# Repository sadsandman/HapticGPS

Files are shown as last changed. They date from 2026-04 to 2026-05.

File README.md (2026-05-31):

# HapticGPS — Wearable Haptic Navigation Board

<p align="center">
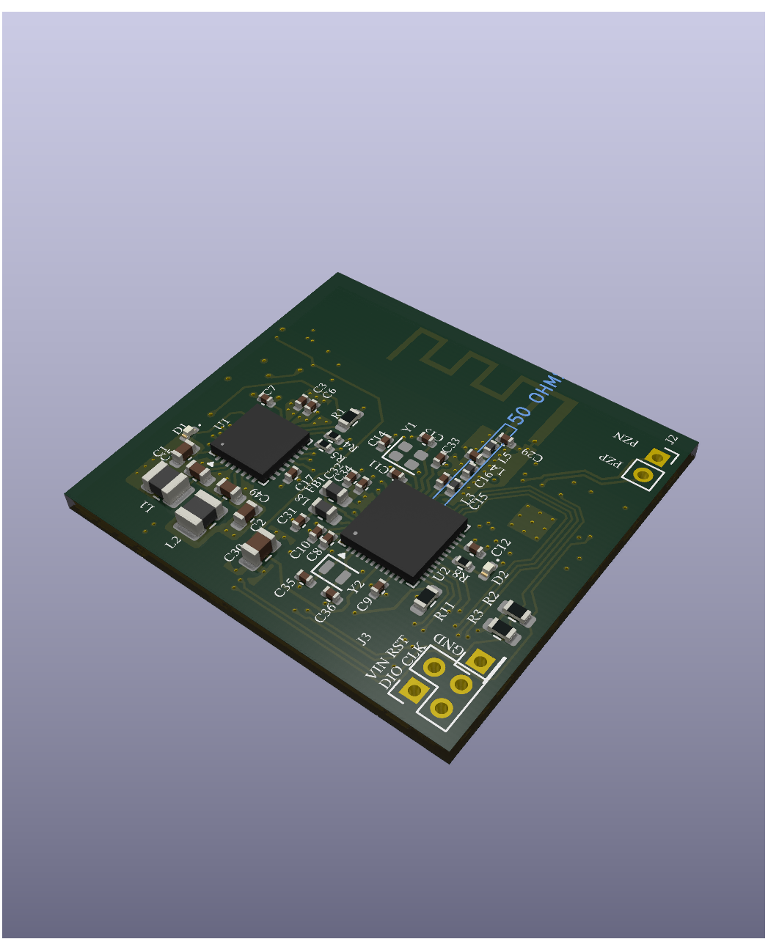
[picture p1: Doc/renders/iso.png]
HapticGPS PCB — isometric view
  
</p>

<p align="center">
  
  
  
  
</p>

A compact 4-layer wearable PCB that delivers directional haptic feedback via a piezoelectric actuator. The board combines a Bluetooth Low Energy SoC, a 6-axis IMU, a piezoelectric haptic driver, non-volatile FRAM storage, and a LiPo power management IC — all in a **30 × 33 mm** footprint.

---

## PCB Views

| Top | Bottom |
|:---:|:---:|
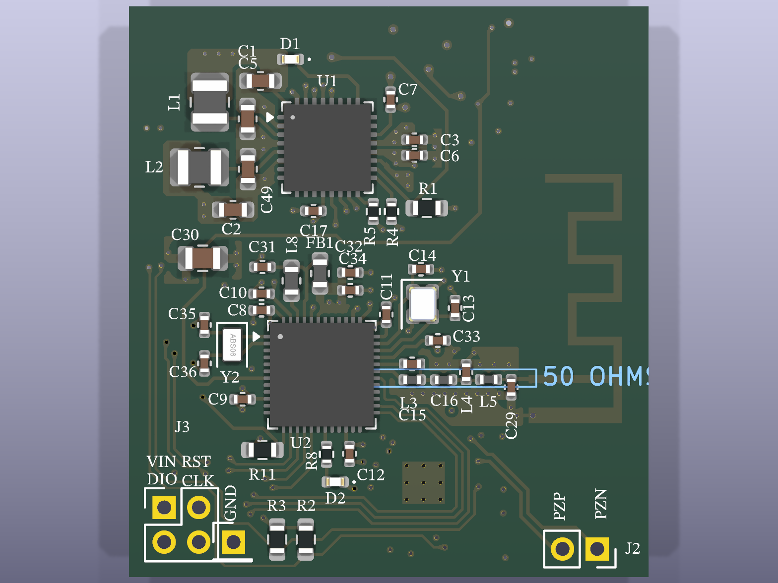
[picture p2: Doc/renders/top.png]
Top view
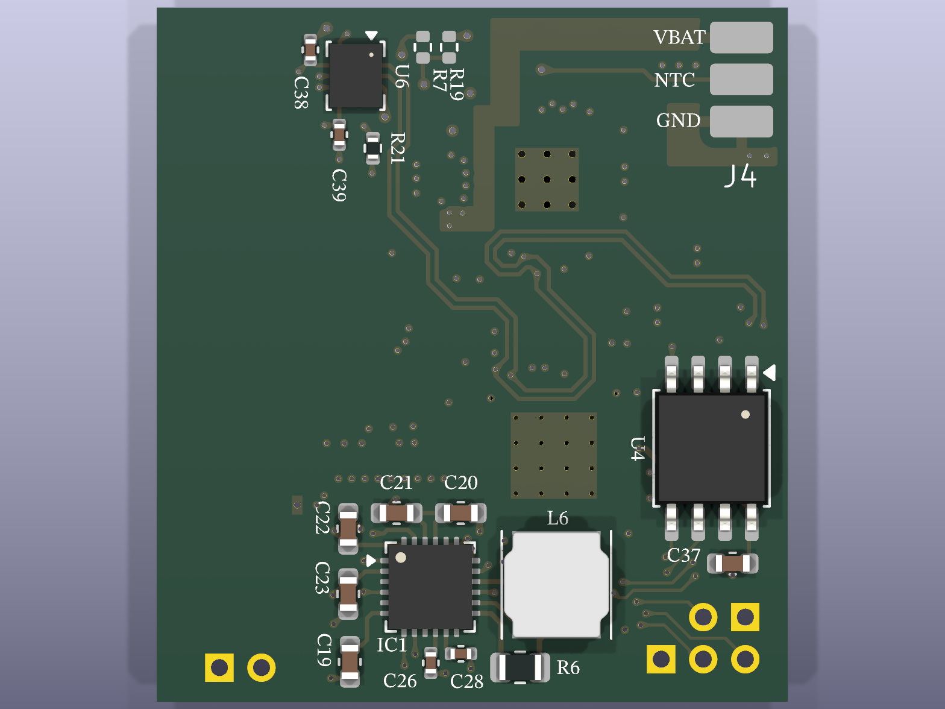
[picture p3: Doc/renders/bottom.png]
Bottom view
|  |  |

---

## Key Features

- **Ultra-low-power BLE 5.4** SoC (Nordic nRF54L15) with on-board PCB trace antenna
- **Piezoelectric haptic feedback** driven by a dedicated high-voltage driver IC (Bosch BOS1921)
- **6-axis IMU** (ST LSM6DSV) for orientation and motion sensing
- **8 Mbit FRAM** (Cypress CY15B108QN) for fast, wear-unlimited non-volatile storage
- **Integrated LiPo charger + dual DCDC + LDO** (Nordic nPM1300 PMIC)
- **4-layer stackup** for clean power planes and antenna isolation
- SWD debug/programming header

---

## Hardware Specifications

| Parameter | Value |
|---|---|
| PCB size | 30 × 33 mm |
| Stackup | 4-layer (F.Cu / In1.Cu / In2.Cu / B.Cu) |
| Board thickness | 1.526 mm |
| Design tool | KiCad 9.0 |
| Revision | V1.0.0 |

---

## Block Diagram

<p align="center">
  System architecture
</p>

---

## Bill of Materials (Key ICs)

| Ref | Part | Description |
|-----|---|---|
| U1 | [Nordic nPM1300](https://www.nordicsemi.com/Products/nPM1300) | PMIC — LiPo charger, dual buck, LDO |
| U2 | [Nordic nRF54L15-QFAA-R](https://www.nordicsemi.com/Products/nRF54L15) | BLE 5.4 SoC, Arm Cortex-M33 |
| U3 | [Bosch BOS1921CQR](https://www.bosch-sensortec.com) | Piezoelectric haptic driver |
| U4 | [Cypress CY15B108QN](https://www.infineon.com/cms/en/product/memories/f-ram-ferroelectric-ram/serial-f-ram/cy15b108qn/) | 8 Mbit SPI FRAM |
| IC1 | [ST LSM6DSV80XTR](https://www.st.com/en/mems-and-sensors/lsm6dsv80x.html) | 6-axis IMU (accel + gyro) |
| Y1/Y2 | Crystal | MCU system & RTC clock references |

---

## Connectors & Interfaces

| Designator | Function | Signals |
|---|---|---|
| J3 | SWD debug header | VIN, RST, DIO, CLK, GND |
| J4 | LiPo battery | VBAT, NTC, GND |
| J2 | Piezo actuator | PZP, PZN |

---

## Getting Started

### Prerequisites

- [KiCad 9.0+](https://www.kicad.org/) to open schematics and PCB layout
- A LiPo cell (connected via J4)
- A piezoelectric actuator (connected via J2)
- An SWD programmer (e.g. J-Link, nRF9160 DK) for firmware flashing

### Opening the Project

```bash
git clone <repo-url>
cd HapticGPS/HapticGPS
kicad HapticGPS.kicad_pro
```

### Generating PCB Renders

Renders are generated with the KiCad CLI:

```bash
# Top view
kicad-cli pcb render \
  --output Doc/renders/top.png \
  --width 1600 --height 1200 \
  --side top --quality high --floor \
  HapticGPS/HapticGPS.kicad_pcb

# Bottom view
kicad-cli pcb render \
  --output Doc/renders/bottom.png \
  --width 1600 --height 1200 \
  --side bottom --quality high --floor \
  HapticGPS/HapticGPS.kicad_pcb

# Isometric view
kicad-cli pcb render \
  --output Doc/renders/iso.png \
  --width 1600 --height 1200 \
  --quality high --floor --perspective \
  --rotate "30,0,45" \
  HapticGPS/HapticGPS.kicad_pcb
```

---

## Repository Structure

```
HapticGPS/
├── HapticGPS/
│   ├── HapticGPS.kicad_pro       # KiCad project file
│   ├── HapticGPS.kicad_pcb       # PCB layout
│   ├── HapticGPS.kicad_sch       # Top-level schematic
│   └── modules/
│       ├── controller.sch.kicad_sch     # MCU + FRAM
│       ├── power.kicad_sch              # PMIC circuit
│       ├── piezoelectric_driver.kicad_sch  # Haptic driver
│       └── (imu.kicad_sch)              # IMU sub-sheet
└── Doc/
    ├── architecture/
    │   └── Basic_architecture.svg
    └── renders/
        ├── top.png
        ├── bottom.png
        └── iso.png
```

---

## License

This hardware design is released under the **CERN Open Hardware Licence Version 2 — Strongly Reciprocal (CERN-OHL-S v2)**.  
See [`LICENSE`](LICENSE) for the full text, or visit [ohwr.org/cern_ohl_s_v2.txt](https://ohwr.org/cern_ohl_s_v2.txt).

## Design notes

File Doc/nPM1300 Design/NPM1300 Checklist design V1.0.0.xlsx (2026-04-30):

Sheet: Schematic checklist
nPM1300 Schematic Checklist |  | Date: | 11.12.2025 |  |  |  |  |  |  | OK
 |  |  |  |  |  |  |  |  |  | NOK
Pin QFN | Pin CSP | Pin Name | Direction | Type | OpMax [V] | AbsMax [V] | Function | Connection | Component spec | Reviewed | Review Notes
1 | B6 | VOUT1 | Input | Analog |  | 5.5 | Buck1 output voltage feedback | Connect to Buck1 output capacitor. Connect to PVDD if not used for biasing it to known level and avoiding leakage. | Capacitance 10uF nominal Min 4uF effective Max 20uF effective Voltage rating 6.3V or higher Increasing capacitance has effect on the startup time and VSYS drop during startup. If both bucks are used they start at the same time and loading to the VSYS rail need to be considered (100mA default current limit). | OK | Check DC bias effect of the capacitor
2 | A7 | PVSS1 |  | Ground | 0 | 0 | Buck1 power stage ground | Connect to GND |  | OK
3 | B7 | SW1 | Output | Power |  | 5.5 | Buck1 switch output to inductor | Connect to output inductor. Leave floating if not used | rr | OK
4 | C7 | PVDD | Input | Power |  | 5.5 | Power input for both buck converters | Connect to VSYS. Must have input capacitor for each used buck. Capacitors must be grounded to PVSS1/PVSS2 accordingly | Capacitance 10uF nominal per buck in use Min 4uF effective Voltage rating 6.3V or higher Consider adding smaller high frequency bypass capacitor for each buck input (10nF or 100nF) for EMI reduction | OK | Check DC bias effect of the capacitor
5 | D7 | SW2 | Output | Power |  | 5.5 | Buck2 switch output to inductor | Connect to output inductor. Leave floating if not used | Inductance 2.2uH (+/-20%) ISAT >350mA ITEMP >200mA DCR < 400mohm
6 | E7 | PVSS2 |  | Ground | 0 | 0 | Buck2 power stage ground | Connect to GND |  | OK
7 | D6 | GPIO0 | Input/output | Digital |  | VDDIO + 0.3 | General purpose IO | User defined. Can be left floating if not used |  | OK
8 | E6 | GPIO1 | Input/output | Digital |  | VDDIO + 0.3 | General purpose IO | User defined. Can be left floating if not used |  | OK
9 | C5 | GPIO2 | Input/output | Digital |  | VDDIO + 0.3 | General purpose IO | User defined. Can be left floating if not used |  | OK
10 | C4 | GPIO3 | Input/output | Digital |  | VDDIO + 0.3 | General purpose IO | User defined. Can be left floating if not used |  | OK
11 | B5 | GPIO4 | Input/output | Digital |  | VDDIO + 0.3 | General purpose IO | User defined. Can be left floating if not used |  | OK
12 | E4 | VDDIO | Input | Power | VSYS | 5.5 | IO reference voltage supply | Should be connected to desired IO voltage level used for TWI bus | Capacitance 100nF nominal Voltage rating 6.3V or higher | OK
13 | E5 | SDA | Input/output | Digital |  | VDDIO + 0.3 | TWI Data line | Pull-up resistor to VDDIO. Connect to GND or VDDIO if not used | Resistor value depends on the bus capacitance and TWI clock frequency | OK
14 | E3 | SCL | Input | Digital |  | VDDIO + 0.3 | TWI Clock line | Pull-up resistor to VDDIO. Connect to GND or VDDIO if not used | Resistor value depends on the bus capacitance and TWI clock frequency | OK
15 | D4 | SHPHLD | Input | Digital |  | 5.5 | Ship hold mode control | Typically push button to GND to allow exiting Ship mode. Can be left floating if not used. There is internal 50kohm pull-up to VBAT. Don't connect to SoC GPIO or similar directly configured as push-pull output. It will can form a leakage path through the internal pull-up resistor. Ok to connect to Open Drain output.
16 | E1 | VSET2 | Input | Analog |  | 5.5 | Set resistor for default Buck2 output voltage | Connect to RVSET2. Connect to GND for disabling Buck2 by default. Note: even if buck is disabled by default it can be enabled with TWI. |  | OK
17 | E2 | VSET1 | Input | Analog |  | 5.5 | Set resistor for default Buck1 output voltage | Connect to RVSET1. Connect to GND for disabling Buck1 by default. Note: even if buck is disabled by default it can be enabled with TWI. |  | OK
18 | D3 | NTC | Input | Analog |  | 5.5 | Battery NTC thermistor input | Connect to battery NTC. If battery pack does not have NTC connect this pin directly or through a resistor to GND. Functionality must be disabled with TWI write. | Parallel capacitance max 100pF | OK | Check battery datasheet for parallel capacitance on the NTC
19 | D1,D2 | VBAT | Input | Power | 4.45 | 5.5 | Battery input | Connect to bypass capacitor and battery | Capacitance 2.2uF nominal recommended Voltage rating 6.3V or higher | OK
20 | C1/C2 | VSYS | Output | Power |  | 5.5 | System regulator output | Connect to PVDD and to VSYS capacitor | Capacitance 10uF nominal 4uF effective minimum Voltage rating 6.3V or higher in addition to the buck input capacitors placed on PVDD Consider adding smaller high frequency bypass capacitor (10nF or 100nF) for EMI reduction | OK | Check DC bias effect of the capacitor
21 | B1, B2 | VBUS | Input | Power | 5.5 | 22 | USB supply | Connect to USB VBUS and VBUSIN capacitor | Capacitance 1uF nominal See USB specification for max capacitance limitations. Check carefully the voltage rating of the capacitor for the use case. Voltage rating of the VBUS pin is 22V and if up to 22V voltage transients are expected the capacitor should be selected accordingly. | NOK
22 | C3 | VBUSOUT | Output | Analog |  | 5.5 | VBUSOUT | Connect to nRF device VBUS. Must have decoupling capacitor even if not used. VBUSOUT is only for host sensing and should not be used as a supply | Capacitance 1uF nominal Voltage rating 6.3V or higher | OK
23 | D5 | CC1 | Input | Analog |  | 5.5 | USB-C Configuration Channel 1 | Connect to USB-C connector CC1. Leave floating if USB-C is not used, or connect to GND. Internal 5.1kohm resistor |  | OK
24 | B3 | CC2 | Input | Analog |  | 5.5 | USB-C Configuration Channel 2 | Connect to USB-C connector CC2. Leave floating if USB-C is not used, or connect to GND. Internal 5.1kohm resistor |  | OK
25 | A1 | LED0 | Output | Analog |  | 5.5 | Led driver 0 output, 5mA constant current sink | Connect to LED cathode. Leave floating if not used |  | OK
26 | A2 | LED1 | Output | Analog |  | 5.5 | Led driver 1 output, 5mA constant current sink | Connect to LED cathode. Leave floating if not used |  | OK
27 | A3 | LED2 | Output | Analog |  | 5.5 | Led driver 2 output, 5mA constant current sink | Connect to LED cathode. Leave floating if not used |  | OK
28 | B4 | LSIN1/VINLDO1 | Input | Power |  | 5.5 | Load switch/LDO1 input | Connect to supply for load switch/LDO1. Connect to GND if not used | Input capacitance depends on what supplies the load switch/LDO. If connected to buck output or VSYS, typically no additional capacitance needed. Minimum input voltage in LDO mode is 2.6V. | OK
29 | A4 | LSOUT1/VOUTLDO1 | Output | Power |  | 5.5 | Load switch/LDO1 output | Connect to output capacitor. Connect to GND if not used | LDO Operation: Capacitance 2x10uF nominal 6uF effective minimum Voltage rating 6.3V or higher LS operation: Capacitance 1uF nominal Voltage rating 6.3V or higher | OK | Check DC bias effect of the capacitor
30 | B5 | LSIN2/VINLDO2 | Input | Power |  | 5.5 | Load switch/LDO2 input | Connect to supply for load switch/LDO2. Connect to GND if not used | Input capacitance depends on what supplies the load switch/LDO. If connected to buck output or VSYS, typically no additional capacitance needed. Minimum input voltage in LDO mode is 2.6V. | OK
31 | A5 | LSOUT2/VOUTLDO2 | Output | Power |  | 5.5 | Load switch/LDO2 output | Connect to output capacitor. Connect to GND if not used | LDO Operation: Capacitance 2x10uF nominal 6uF effective minimum Voltage rating 6.3V or higher LS operation: Capacitance 1uF nominal Voltage rating 6.3V or higher | OK | Check DC bias effect of the capacitor
32 | C6 | VOUT2 | Input | Analog |  | 5.5 | Buck2 output voltage feedback | Connect to Buck2 output capacitor. Connect to PVDD if not used for biasing it to known level and avoiding leakage. | Capacitance 10uF nominal Min 4uF effective Max 20uF effective Voltage rating 6.3V or higher Increasing capacitance has effect on the startup time and VSYS drop during startup. If both bucks are used they start at the same time and loading to the VSYS rail need to be considered (100mA default current limit). | OK
DAP | A6 | AVSS |  | Ground | 0 | 0 | Analog/Digital ground | Connect to GND plane |  | OK
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

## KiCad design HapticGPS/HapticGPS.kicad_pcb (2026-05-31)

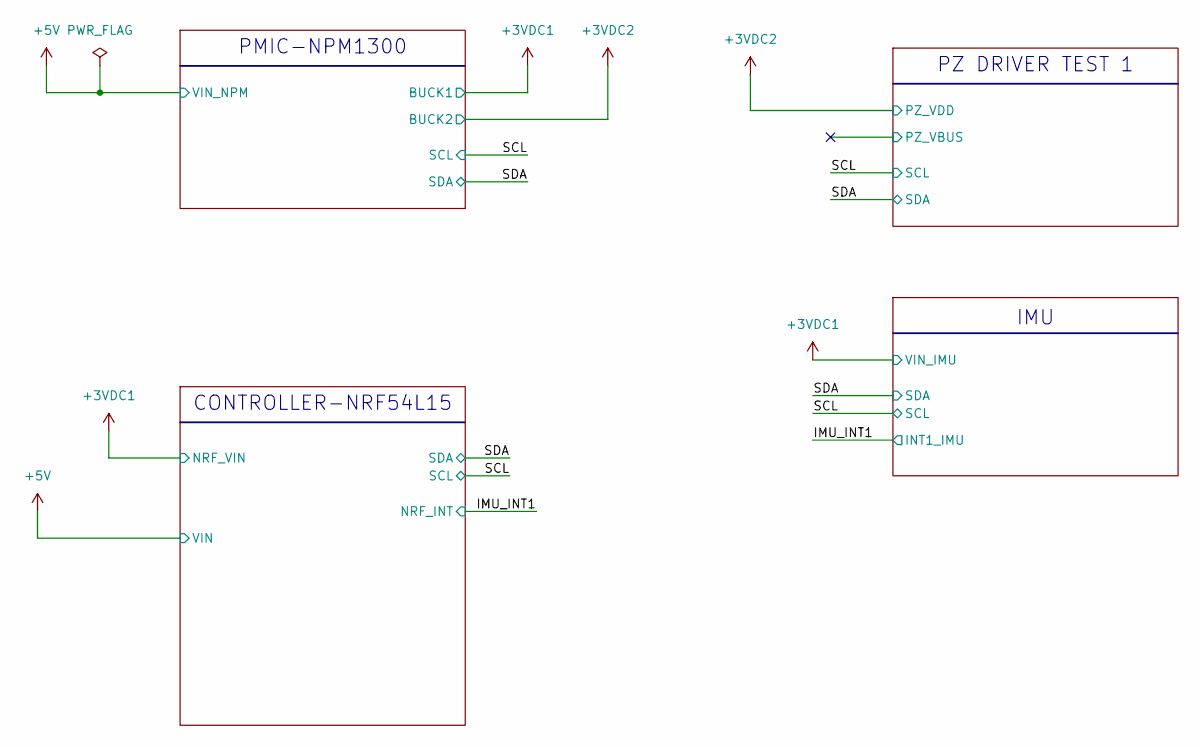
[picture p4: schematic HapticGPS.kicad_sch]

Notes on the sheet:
PMIC-NPM1300
IMU
PZ DRIVER TEST 1
CONTROLLER-NRF54L15

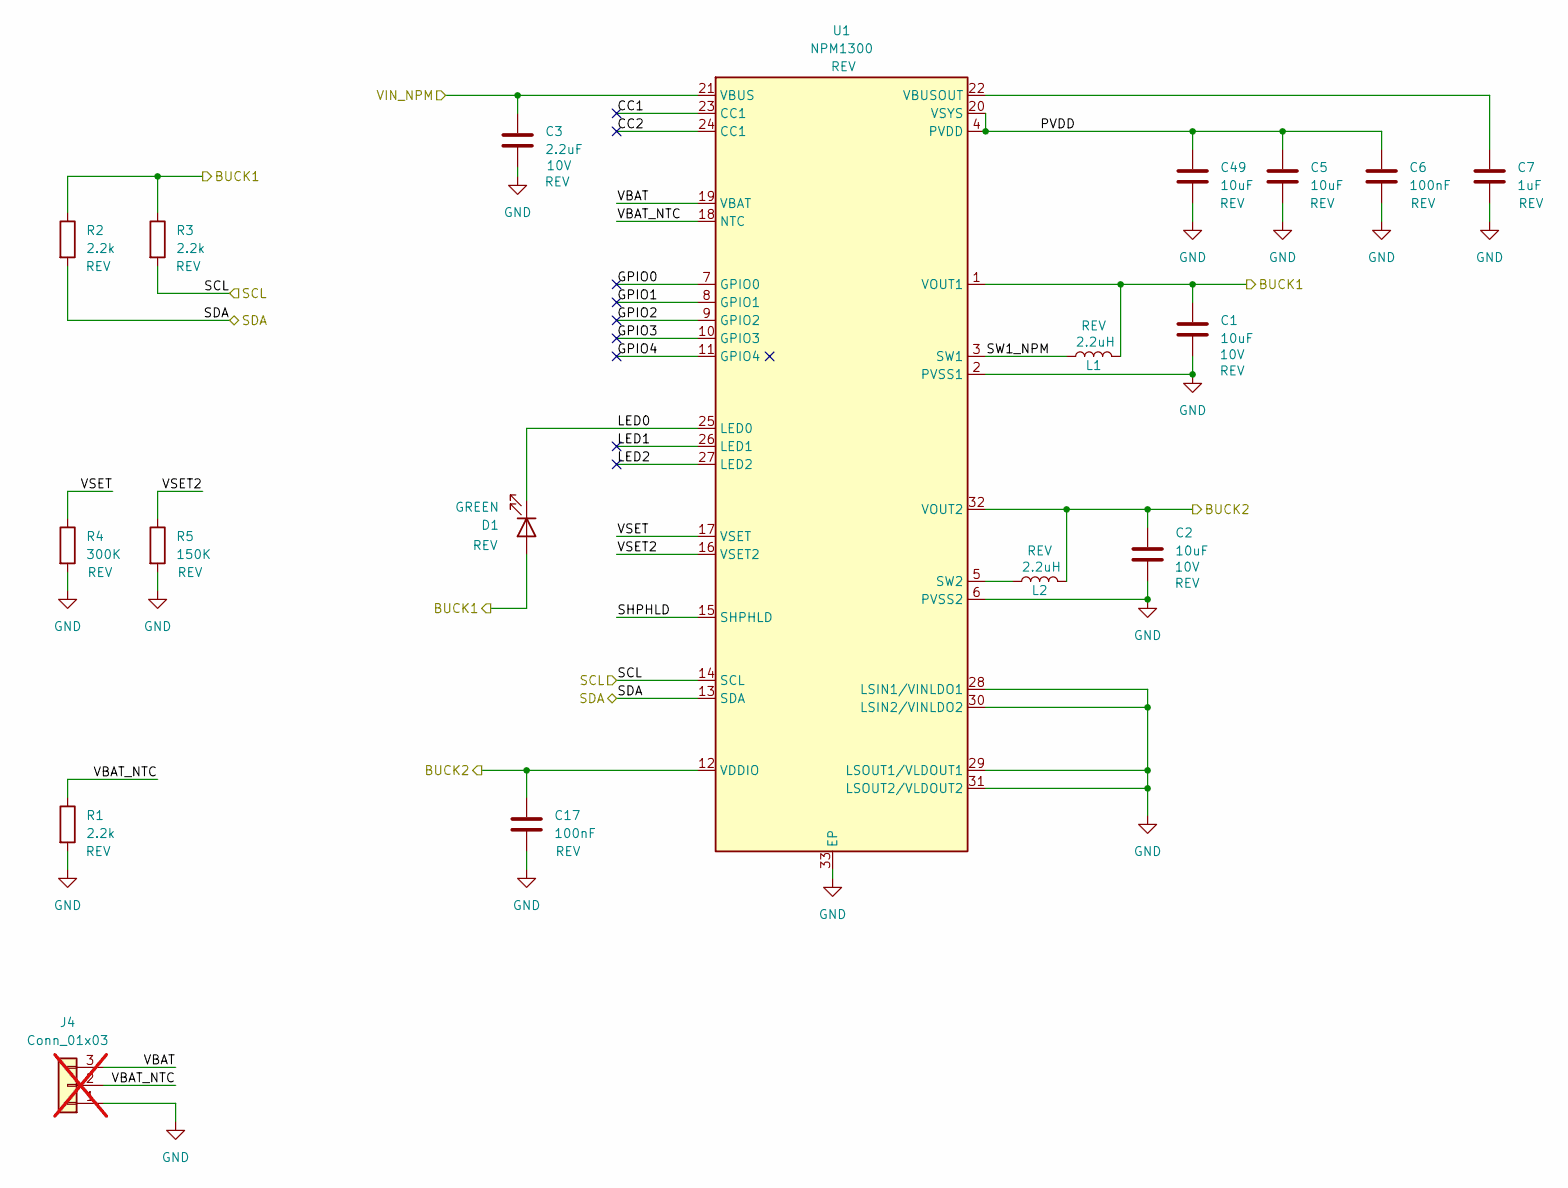
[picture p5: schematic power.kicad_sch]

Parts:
C1, C2: 10uF; C_0603_1608Metric; Voltage 10V
C3: 2.2uF; C_0402_1005Metric; Voltage 10V
C5, C49: 10uF; C_0603_1608Metric
C6, C17: 100nF; C_0402_1005Metric
C7: 1uF; C_0402_1005Metric
D1: GREEN; LED_0402_1005Metric
J4: Conn_01x03; 01x03_1.5x3; not fitted
L1, L2: 2.2uH; L_1008_2520Metric
R1, R2, R3: 2.2k; R_0603_1608Metric
R4: 300K; R_0402_1005Metric
R5: 150K; R_0402_1005Metric
U1: NPM1300; VQFN-32-1EP_5x5mm_P0.5mm_EP3.1x3.1mm_ThermalVias

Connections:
+3VDC1: C1.1, D1.2 (A), L1.2, R2.1, R3.1, U1.1 (VOUT1); also elsewhere on the board
+3VDC2: C2.1, C17.1, L2.2, U1.12 (VDDIO), U1.32 (VOUT2); also elsewhere on the board
+5V: C3.1, U1.21 (VBUS); also elsewhere on the board
/POWER/CC1: U1.23 (CC1)
/POWER/CC2: U1.24 (CC1)
/POWER/GPIO0: U1.7 (GPIO0)
/POWER/GPIO1: U1.8 (GPIO1)
/POWER/GPIO2: U1.9 (GPIO2)
/POWER/GPIO3: U1.10 (GPIO3)
/POWER/GPIO4: U1.11 (GPIO4)
/POWER/LED0: D1.1 (K), U1.25 (LED0)
/POWER/LED1: U1.26 (LED1)
/POWER/LED2: U1.27 (LED2)
/POWER/PVDD: C5.1, C6.1, C49.1, U1.4 (PVDD), U1.20 (VSYS)
/POWER/SHPHLD: U1.15 (SHPHLD)
/POWER/SW1_NPM: L1.1, U1.3 (SW1)
/POWER/VBAT: J4.3, U1.19 (VBAT)
/POWER/VBAT_NTC: J4.2, R1.1, U1.18 (NTC)
/POWER/VSET: R4.1, U1.17 (VSET)
/POWER/VSET2: R5.1, U1.16 (VSET2)
/SCL: R3.2, U1.14 (SCL); also elsewhere on the board
/SDA: R2.2, U1.13 (SDA); also elsewhere on the board
GND: C1.2, C2.2, C3.2, C5.2, C6.2, C7.2, C17.2, C49.2, J4.1, R1.2, R4.2, R5.2, U1.2 (PVSS1), U1.6 (PVSS2), U1.28 (LSIN1/VINLDO1), U1.29 (LSOUT1/VLDOUT1), U1.30 (LSIN2/VINLDO2), U1.31 (LSOUT2/VLDOUT2), U1.33 (EP); also elsewhere on the board
unnamed: L2.1, U1.5 (SW2)
unnamed: C7.1, U1.22 (VBUSOUT)

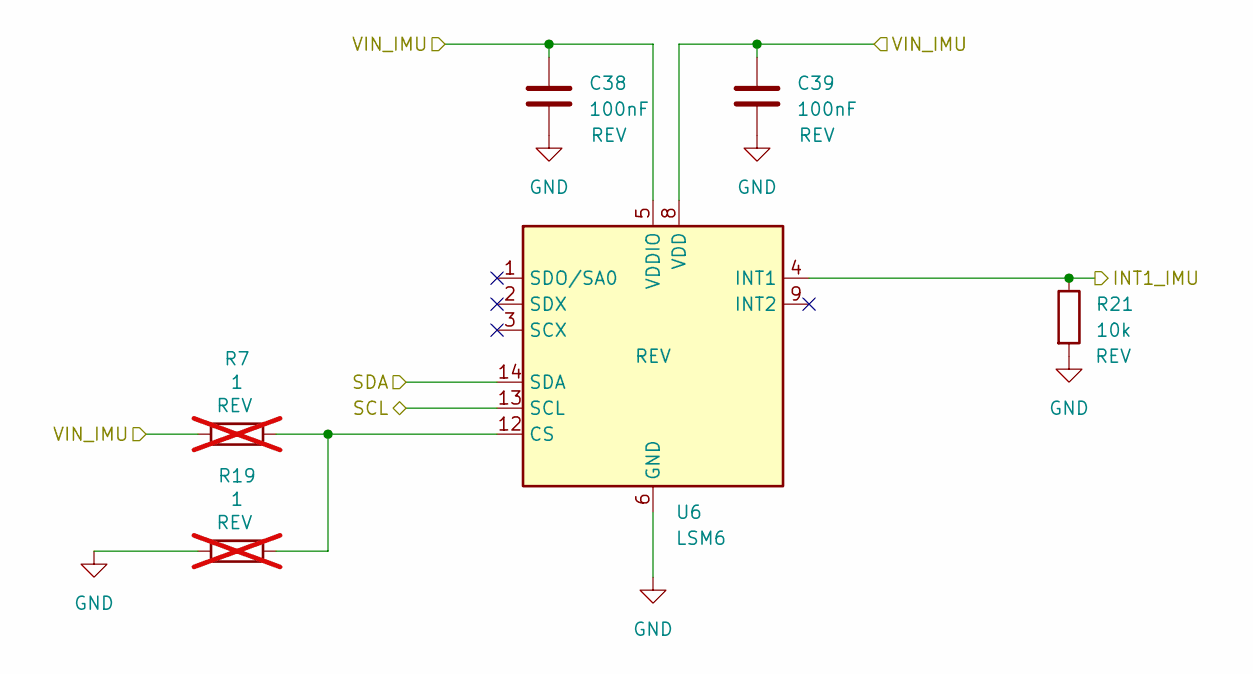
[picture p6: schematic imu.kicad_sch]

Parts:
C38, C39: 100nF; C_0402_1005Metric
R7, R19: 1; R_0402_1005Metric; not fitted
R21: 10k; R_0402_1005Metric
U6: LSM6; LGA-14_3x2.5mm_P0.5mm_LayoutBorder3x4y

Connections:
+3VDC1: C38.1, C39.1, R7.1, U6.5 (VDDIO), U6.8 (VDD); also elsewhere on the board
/IMU_INT1: R21.1, U6.4 (INT1); also elsewhere on the board
/SCL: U6.13 (SCL); also elsewhere on the board
/SDA: U6.14 (SDA); also elsewhere on the board
GND: C38.2, C39.2, R19.1, R21.2, U6.6 (GND), U6.7 (GND); also elsewhere on the board
unnamed: R7.2, R19.2, U6.12 (CS)

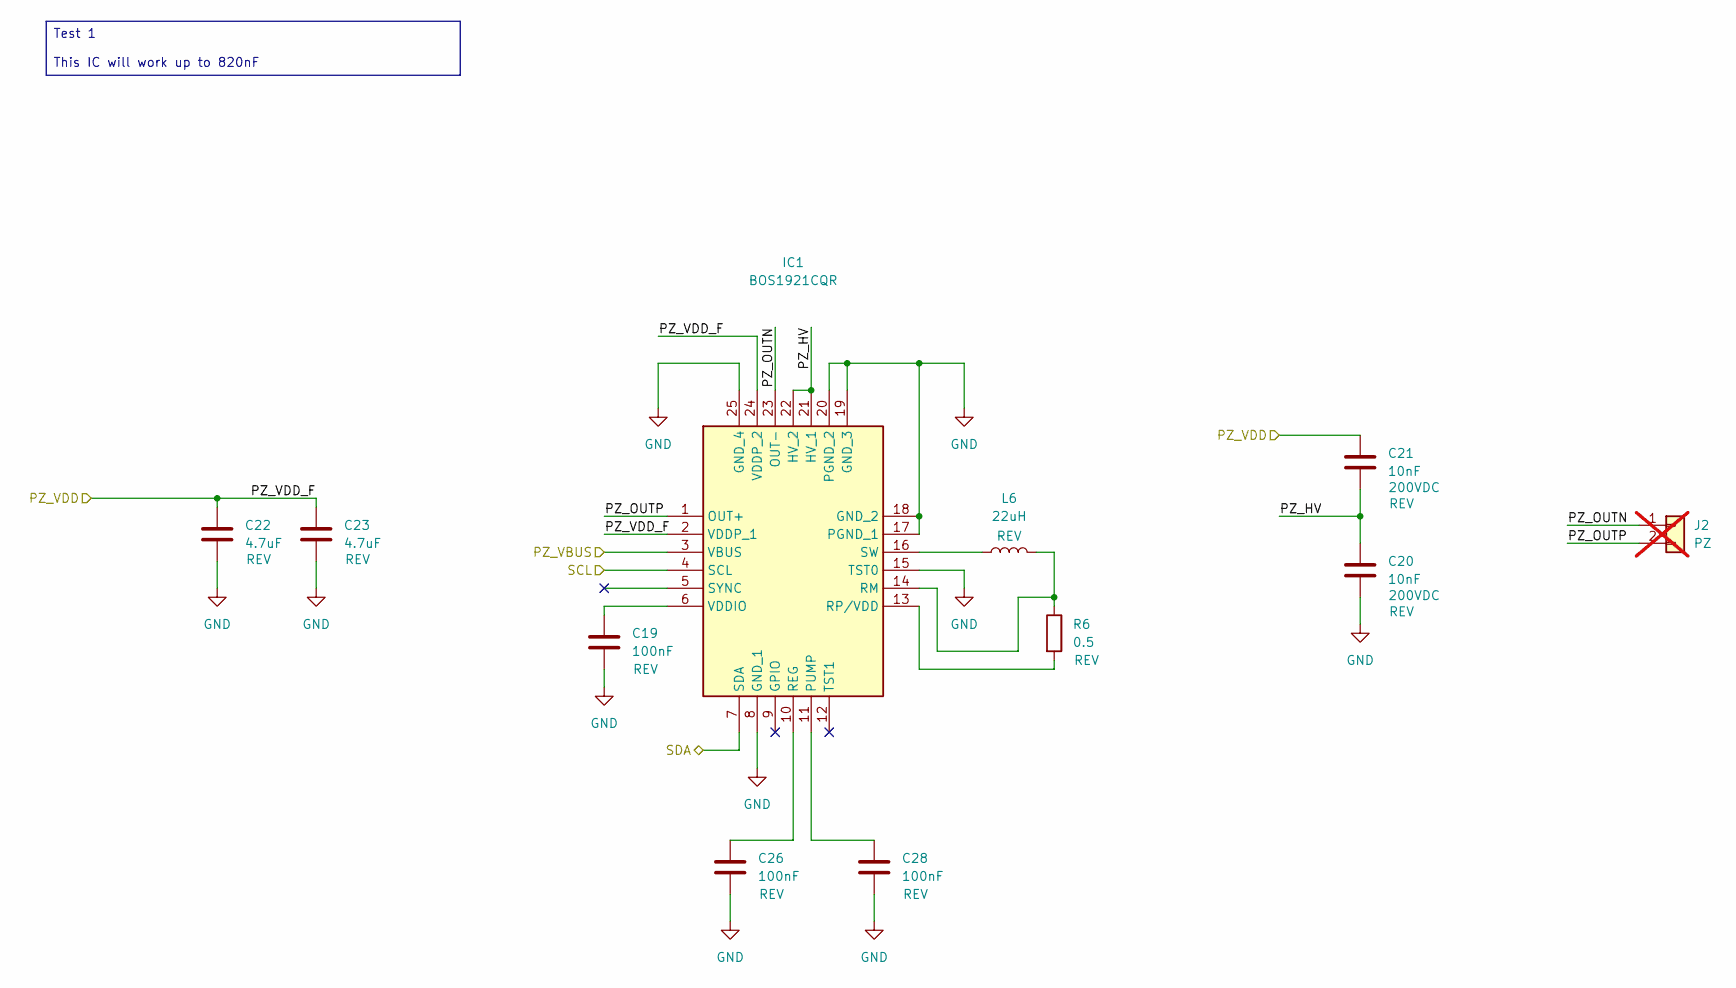
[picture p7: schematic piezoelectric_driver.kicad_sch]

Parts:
C19: 100nF; C_0603_1608Metric
C20, C21: 10nF; C_0603_1608Metric; Voltage 200VDC
C22, C23: 4.7uF; C_0603_1608Metric
C26, C28: 100nF; C_0402_1005Metric
IC1: BOS1921CQR; VQFN-24-1EP_4x4mm_P0.5mm_EP2.45x2.45mm_ThermalVias
J2: PZ; PinSocket_1x02_P2.00mm_Vertical; not fitted
L6: 22uH; L_Taiyo-Yuden_MD-5050
R6: 0.5; R_0805_2012Metric

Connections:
+3VDC2: C21.1, C22.2, C23.2, IC1.2 (VDDP_1), IC1.24 (VDDP_2); also elsewhere on the board
/PIEZOELECTRIC DRIVER/PZ_HV: C20.1, C21.2, IC1.21 (HV_1), IC1.22 (HV_2)
/PIEZOELECTRIC DRIVER/PZ_OUTN: IC1.23 (OUT-), J2.1
/PIEZOELECTRIC DRIVER/PZ_OUTP: IC1.1 (OUT+), J2.2
/PIEZOELECTRIC DRIVER/PZ_VBUS: IC1.3 (VBUS)
/SCL: IC1.4 (SCL); also elsewhere on the board
/SDA: IC1.7 (SDA); also elsewhere on the board
GND: C19.2, C20.2, C22.1, C23.1, C26.2, C28.2, IC1.8 (GND_1), IC1.15 (TST0), IC1.17 (PGND_1), IC1.18 (GND_2), IC1.19 (GND_3), IC1.20 (PGND_2), IC1.25 (GND_4); also elsewhere on the board
unnamed: C28.1, IC1.11 (PUMP)
unnamed: C26.1, IC1.10 (REG)
unnamed: IC1.14 (RM), L6.2, R6.1
unnamed: IC1.13 (RP/VDD), R6.2
unnamed: IC1.16 (SW), L6.1
unnamed: C19.1, IC1.6 (VDDIO)

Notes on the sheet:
Test 1 This IC will work up to 820nF

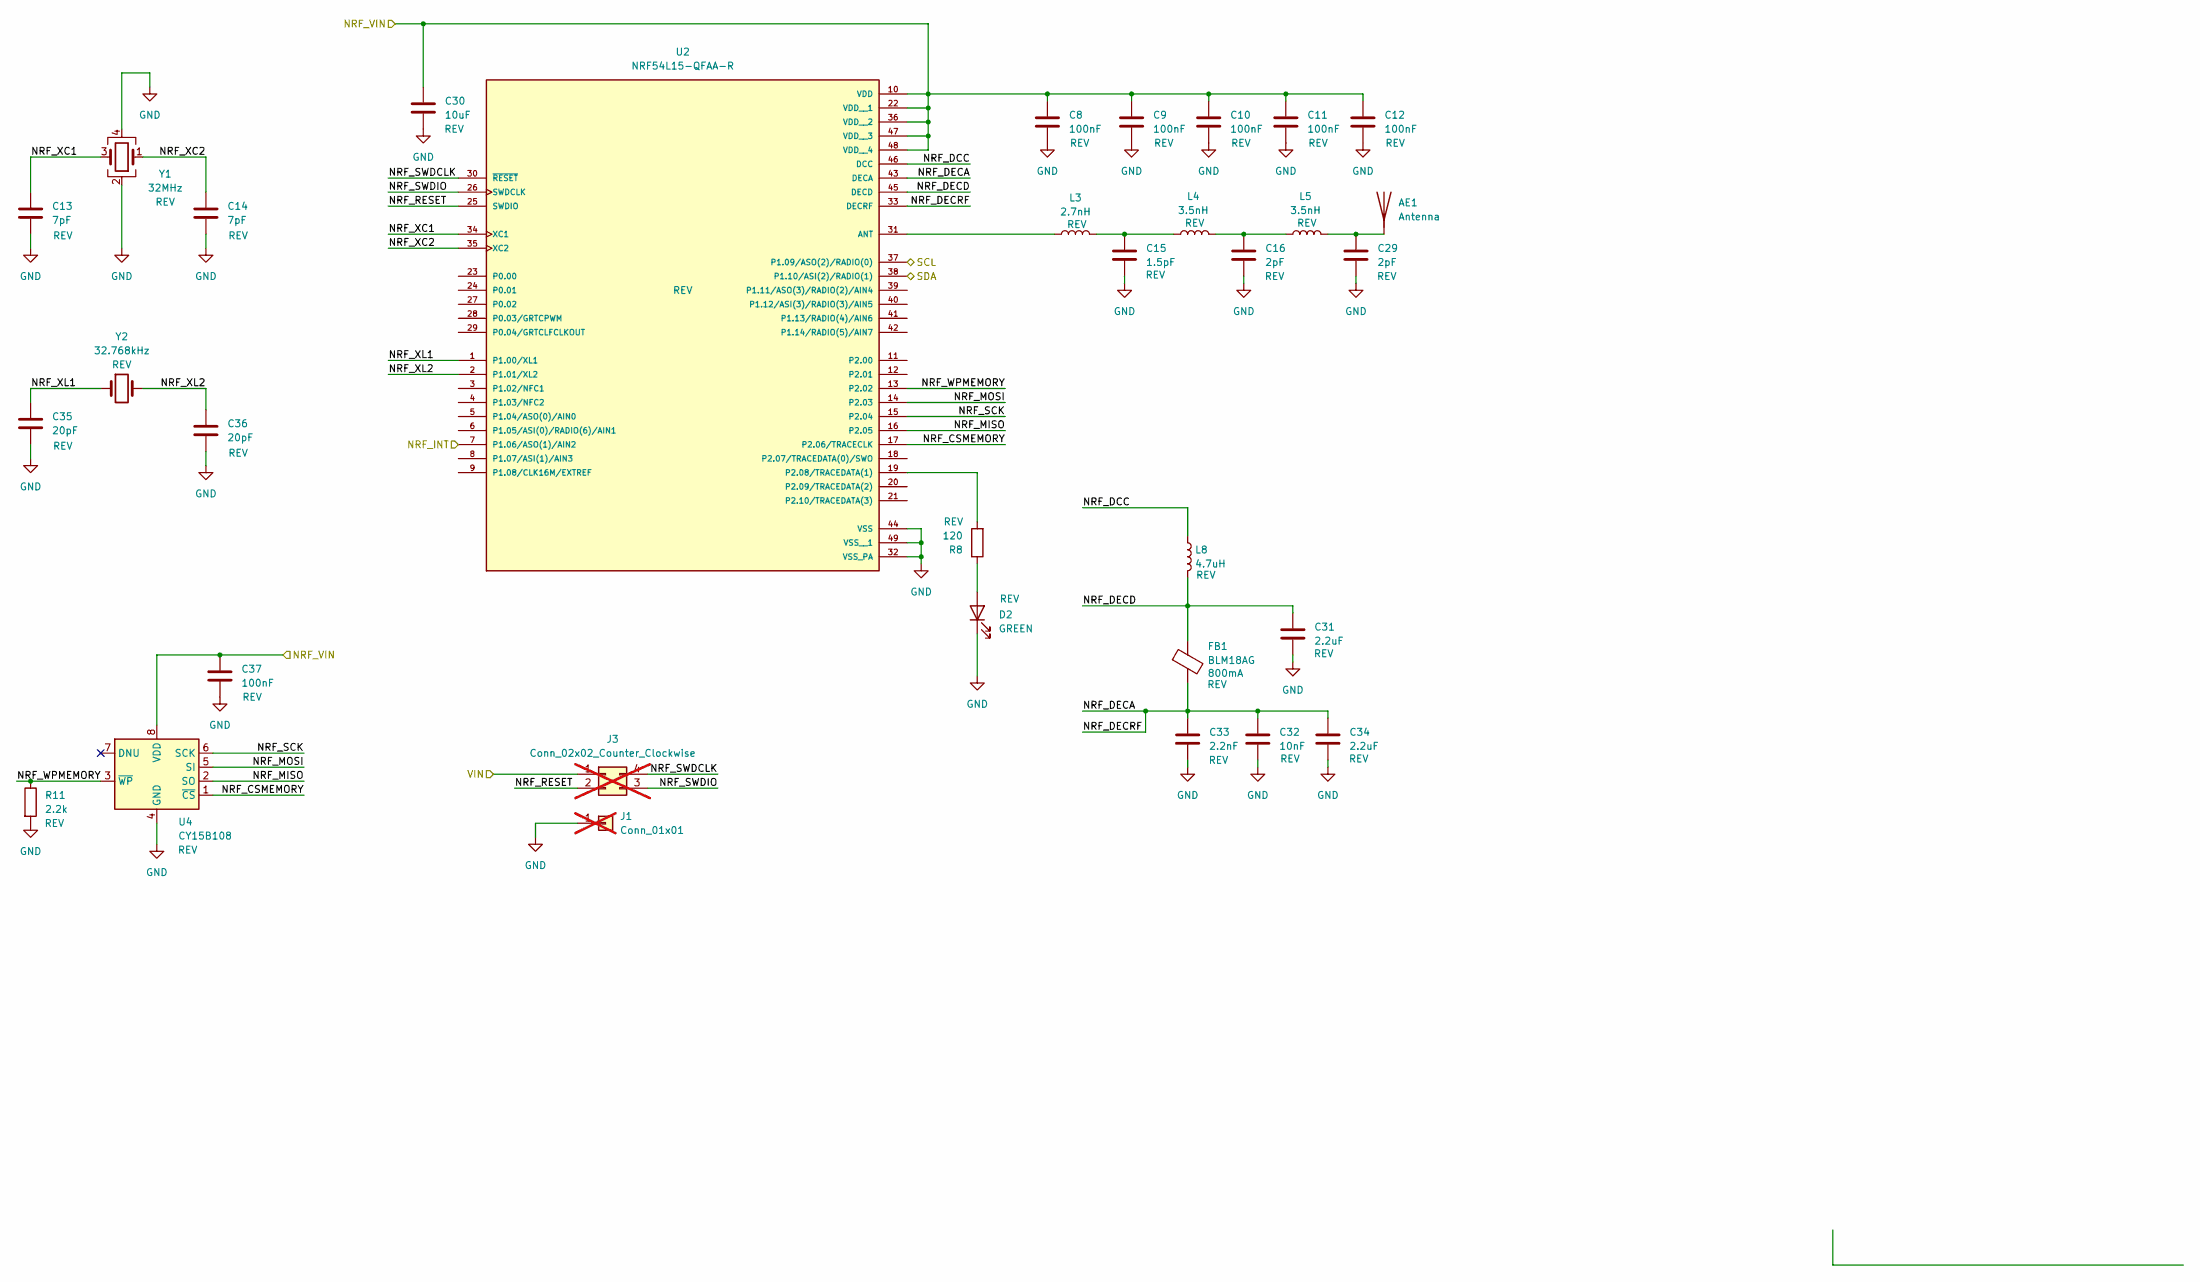
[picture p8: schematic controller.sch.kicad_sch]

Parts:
AE1: Antenna; Texas_SWRA117D_2.4GHz_Left
C8, C9, C10, C11, C12: 100nF; C_0402_1005Metric
C13, C14: 7pF; C_0402_1005Metric
C15: 1.5pF; C_0402_1005Metric
C16, C29: 2pF; C_0402_1005Metric
C30: 10uF; C_0805_2012Metric
C31, C34: 2.2uF; C_0402_1005Metric
C32: 10nF; C_0402_1005Metric
C33: 2.2nF; C_0402_1005Metric
C35, C36: 20pF; C_0402_1005Metric
C37: 100nF; C_0603_1608Metric
D2: GREEN; LED_0402_1005Metric
FB1: BLM18AG; L_0603_1608Metric
J1: Conn_01x01; PinHeader_1x01_P2.00mm_Vertical; not fitted
J3: Conn_02x02_Counter_Clockwise; not fitted
L3: 2.7nH; L_0402_1005Metric
L4, L5: 3.5nH; L_0402_1005Metric
L8: 4.7uH; L_0603_1608Metric
R8: 120; R_0402_1005Metric
R11: 2.2k; R_0603_1608Metric
U2: NRF54L15-QFAA-R; QFN-48-1EP_6x6mm_P0.4mm_EP4.6x4.6mm_ThermalVias; PARTREV 0.8
U4: CY15B108; SOIC-8_5.3x5.3mm_P1.27mm
Y1: 32MHz; Crystal_SMD_2016-4Pin_2.0x1.6mm
Y2: 32.768kHz; Crystal_SMD_2012-2Pin_2.0x1.2mm

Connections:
+3VDC1: C8.1, C9.1, C10.1, C11.1, C12.1, C30.1, C37.1, U2.10 (VDD), U2.22 (VDD__1), U2.36 (VDD__2), U2.47 (VDD__3), U2.48 (VDD__4), U4.8 (VDD); also elsewhere on the board
+5V: J3.1; also elsewhere on the board
/CONTROLLER/NRF_CSMEMORY: U2.17 (P2.06/TRACECLK), U4.1 (~CS)
/CONTROLLER/NRF_DCC: L8.1, U2.46 (DCC)
/CONTROLLER/NRF_DECA: C32.1, C33.1, C34.1, FB1.2, U2.33 (DECRF), U2.43 (DECA)
/CONTROLLER/NRF_DECD: C31.1, FB1.1, L8.2, U2.45 (DECD)
/CONTROLLER/NRF_MISO: U2.16 (P2.05), U4.2 (SO)
/CONTROLLER/NRF_MOSI: U2.14 (P2.03), U4.5 (SI)
/CONTROLLER/NRF_RESET: J3.2, U2.25 (SWDIO)
/CONTROLLER/NRF_SCK: U2.15 (P2.04), U4.6 (SCK)
/CONTROLLER/NRF_SWDCLK: J3.4, U2.30 (~RESET)
/CONTROLLER/NRF_SWDIO: J3.3, U2.26 (SWDCLK)
/CONTROLLER/NRF_WPMEMORY: R11.1, U2.13 (P2.02), U4.3 (~WP)
/CONTROLLER/NRF_XC1: C13.1, U2.34 (XC1), Y1.3
/CONTROLLER/NRF_XC2: C14.1, U2.35 (XC2), Y1.1
/CONTROLLER/NRF_XL1: C35.1, U2.1 (P1.00/XL1), Y2.1
/CONTROLLER/NRF_XL2: C36.1, U2.2 (P1.01/XL2), Y2.2
/IMU_INT1: U2.7 (P1.06/ASO(1)/AIN2); also elsewhere on the board
/SCL: U2.37 (P1.09/ASO(2)/RADIO(0)); also elsewhere on the board
/SDA: U2.38 (P1.10/ASI(2)/RADIO(1)); also elsewhere on the board
GND: AE1.2, C8.2, C9.2, C10.2, C11.2, C12.2, C13.2, C14.2, C15.2, C16.2, C29.2, C30.2, C31.2, C32.2, C33.2, C34.2, C35.2, C36.2, C37.2, D2.1 (K), J1.1, R11.2, U2.32 (VSS_PA), U2.44 (VSS), U2.49 (VSS__1), U4.4 (GND), Y1.2, Y1.4; also elsewhere on the board
unnamed: AE1.1 (A), C29.1, L5.2
unnamed: C15.1, L3.2, L4.1
unnamed: C16.1, L4.2, L5.1
unnamed: D2.2 (A), R8.1
unnamed: L3.1, U2.31 (ANT)
unnamed: R8.2, U2.19 (P2.08/TRACEDATA(1))

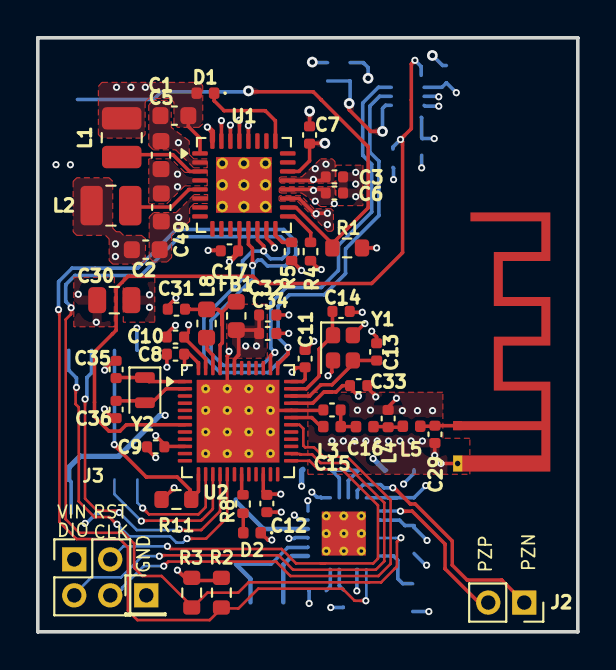
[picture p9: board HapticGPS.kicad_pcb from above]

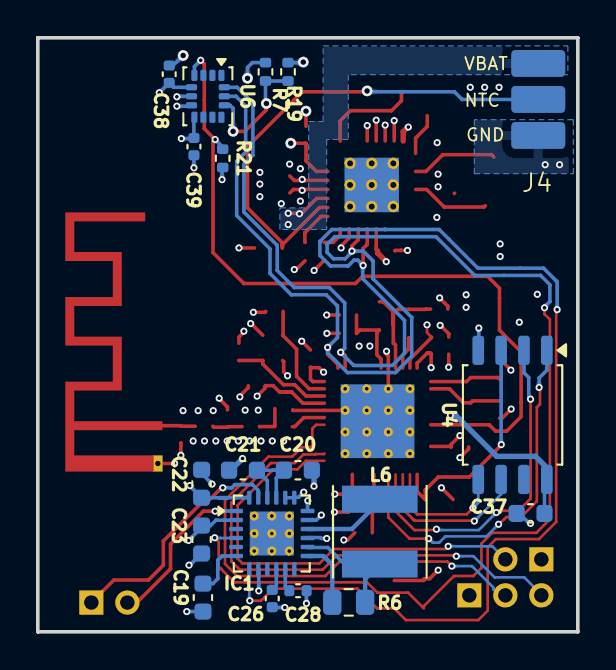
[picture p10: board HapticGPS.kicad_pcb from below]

Board: 4 copper layers, 30.0 x 33.0 mm, 68 parts (19 on the bottom side), 47 nets.

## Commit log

2026-05-31 eliminating GPS, and second piezo driver
    [HapticGPS.kicad_pcb, HapticGPS.kicad_sch, controller.sch.kicad_sch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]
2026-05-31 add README, LICENSE, and PCB renders
    Includes raytraced top/bottom/isometric renders generated with kicad-cli,
    a full project README with board specs and BoM, and CERN-OHL-S v2 license.
2026-05-31 update top and bottom PCB renders with new 3D models
2026-05-31 Corecting iso
    [HapticGPS.kicad_pcb]

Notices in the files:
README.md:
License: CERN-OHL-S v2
